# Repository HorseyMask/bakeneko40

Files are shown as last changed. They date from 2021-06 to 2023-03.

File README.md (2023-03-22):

# bakeneko40

## On Hold / WIP. Nothing here works (probably), please don't actually try to make this

### Do have interest in working on this again, but still consider this on hold until further work is done.

40% verison of the bakenkeo40 keyboard by kkatano. 

PCB is still in testing and unconfirmed to work, but otherwise project is mostly done.

Case is a bit too big for plate and pcb. Either edit case or use foam between pcb and plate to allow more room for oring.

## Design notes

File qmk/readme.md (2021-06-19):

# bakeuma40

bakeuma40

*A short description of the keyboard/project*

* Keyboard Maintainer: [Horace](https://github.com/yourusername)
* Hardware Supported: *The PCBs, controllers supported*
* Hardware Availability: *Links to where you can find this hardware*

Make example for this keyboard (after setting up your build environment):

    make bakeuma40:default

Flashing example for this keyboard:

    make bakeuma40:default:flash

See the [build environment setup](https://docs.qmk.fm/#/getting_started_build_tools) and the [make instructions](https://docs.qmk.fm/#/getting_started_make_guide) for more information. Brand new to QMK? Start with our [Complete Newbs Guide](https://docs.qmk.fm/#/newbs).

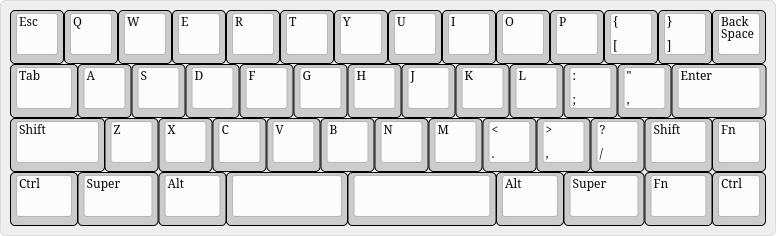
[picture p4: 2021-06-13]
keyboard-layout.png

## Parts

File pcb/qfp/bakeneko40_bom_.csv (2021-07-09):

Component | Description | Part | References | Value | Footprint | Quantity Per PCB | Datasheet
1 | Unpolarized capacitor, small symbol | C_Small | C6 C7 | 22pF | C_0805_2012Metric | 2 | ~
2 | Unpolarized capacitor, small symbol | C_Small | C2 C3 C4 | 0.1uF | C_0805_2012Metric | 3 | ~
3 | Unpolarized capacitor, small symbol | C_Small | C1 | 1uF | C_0805_2012Metric | 1 | ~
4 | Unpolarized capacitor, small symbol | C_Small | C5 | 10uF | C_0805_2012Metric | 1 | ~
5 | Diode, small symbol | D_Small | D1 D2 D3 D4 D5 D6 D7 D8 D9 D10 D11 D12 D13 D14 D15 D16 D17 D18 D19 D20 D21 D22 D23 D24 D25 D26 D27 D28 D29 D30 D31 D32 D33 D34 D35 D36 D37 D38 D39 D40 D41 D42 D43 D44 D45 D46 D47 D48 D49 | SOD-123 | D_SOD-123 | 49 | ~
6 | Resettable fuse, polymeric positive temperature coefficient, small symbol | Polyfuse_Small | F1 | 500mA | Fuse_1206_3216Metric | 1 | ~
7 | Atmel 6-pin ISP connector | AVR-ISP-6 | J2 | AVR-ISP-6 | Reset_Pretty-Mask | 1 | ~
8 | Generic connector, single row, 01x04, script generated (kicad-library-utils/schlib/autogen/connector/) | Conn_01x04 | J1 | JST SH 4-pin | JST-SR-4 | 1 | ~
9 |  | MX-NoLED | MX1 MX2 MX3 MX4 MX5 MX6 MX7 MX8 MX9 MX10 MX11 MX12 MX13 MX14 MX16 MX17 MX18 MX19 MX20 MX21 MX22 MX23 MX24 MX25 MX26 MX29 MX30 MX31 MX32 MX33 MX34 MX35 MX36 MX37 MX38 MX40 MX49 | MX-NoLED | MXOnly-1U-NoLED | 37
10 |  | MX-NoLED | MX15 MX39 MX41 MX43 MX46 MX48 | MX-NoLED | MXOnly-1.25U-NoLED | 6
11 |  | MX-NoLED | MX27 MX28 | MX-NoLED | MXOnly-1.75U-NoLED | 2
12 |  | MX-NoLED | MX42 MX47 | MX-NoLED | MXOnly-1.5U-NoLED | 2
13 |  | MX-NoLED | MX44 | MX-NoLED | MXOnly-2.25U-ReversedStabilizers-NoLED | 1
14 |  | MX-NoLED | MX45 | MX-NoLED | MXOnly-2.75U-ReversedStabilizers-NoLED | 1
15 | Resistor, small symbol | R_Small | R2 R3 | 22 | R_0805_2012Metric | 2 | ~
16 | Resistor, small symbol | R_Small | R1 R4 | 10k | R_0805_2012Metric | 2 | ~
17 | Push button switch, generic, two pins | SW_Push | SW1 | SW_Push | SKQG-1155865 | 1 | ~
18 | 16MHz, 32kB Flash, 1kB SRAM, 1kB EEPROM, TQFP-32 | ATmega32U2-AU | U1 | ATmega32U2-AU | TQFP-32_7x7mm_P0.8mm | 1 | http://ww1.microchip.com/downloads/en/DeviceDoc/doc7799.pdf
19 | ESD Protection Diodes with Low Clamping Voltage, SOT-23-6 | SRV05-4 | U2 | SRV05-4 | SOT-23-6 | 1 | http://www.onsemi.com/pub/Collateral/SRV05-4-D.PDF
20 | Four pin crystal, GND on pins 2 and 4, small symbol | Crystal_GND24_Small | Y1 | 16MHz | Crystal_SMD_3225-4Pin_3.2x2.5mm | 1 | ~
Component Groups: | 20
Component Count: | 116
Fitted Components: | 116
Number of PCBs: | 1
Total components: | 116
Schematic Version:
Schematic Date:
PCB Variant: | default
BoM Date: | Fri 09 Jul 2021 03:37:36 PM KST
Schematic Source: | bakeneko40.sch
KiCad Version: | Eeschema 5.1.10

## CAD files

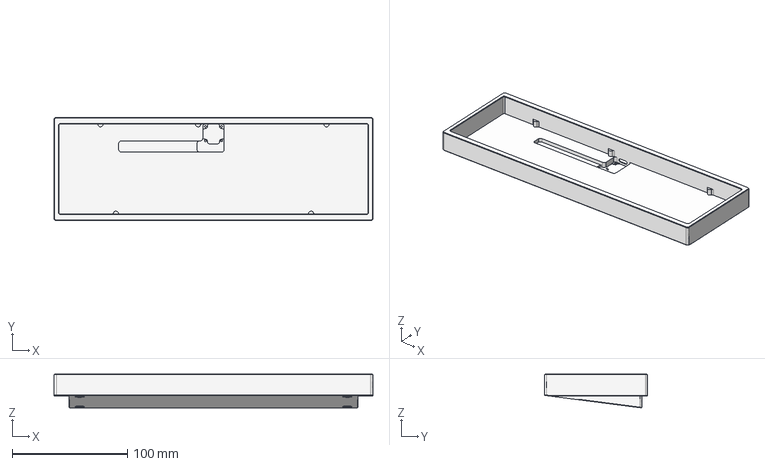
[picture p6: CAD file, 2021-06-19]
case/bakeneko40.step
277.1 x 89.6 x 29.4 mm

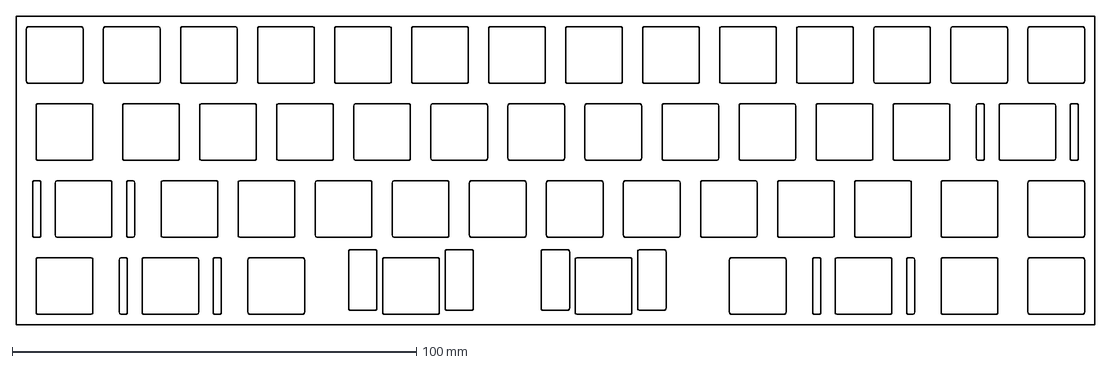
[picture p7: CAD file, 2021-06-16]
plate/bake40_normal.dxf
266.7 x 76.2 mm

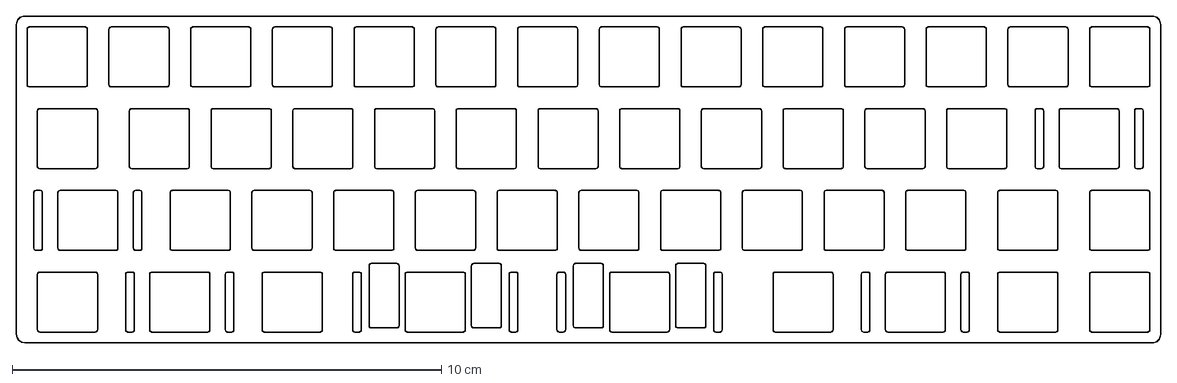
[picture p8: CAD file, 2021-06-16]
plate/bake40_extreme.dxf
26.7 x 7.62 cm

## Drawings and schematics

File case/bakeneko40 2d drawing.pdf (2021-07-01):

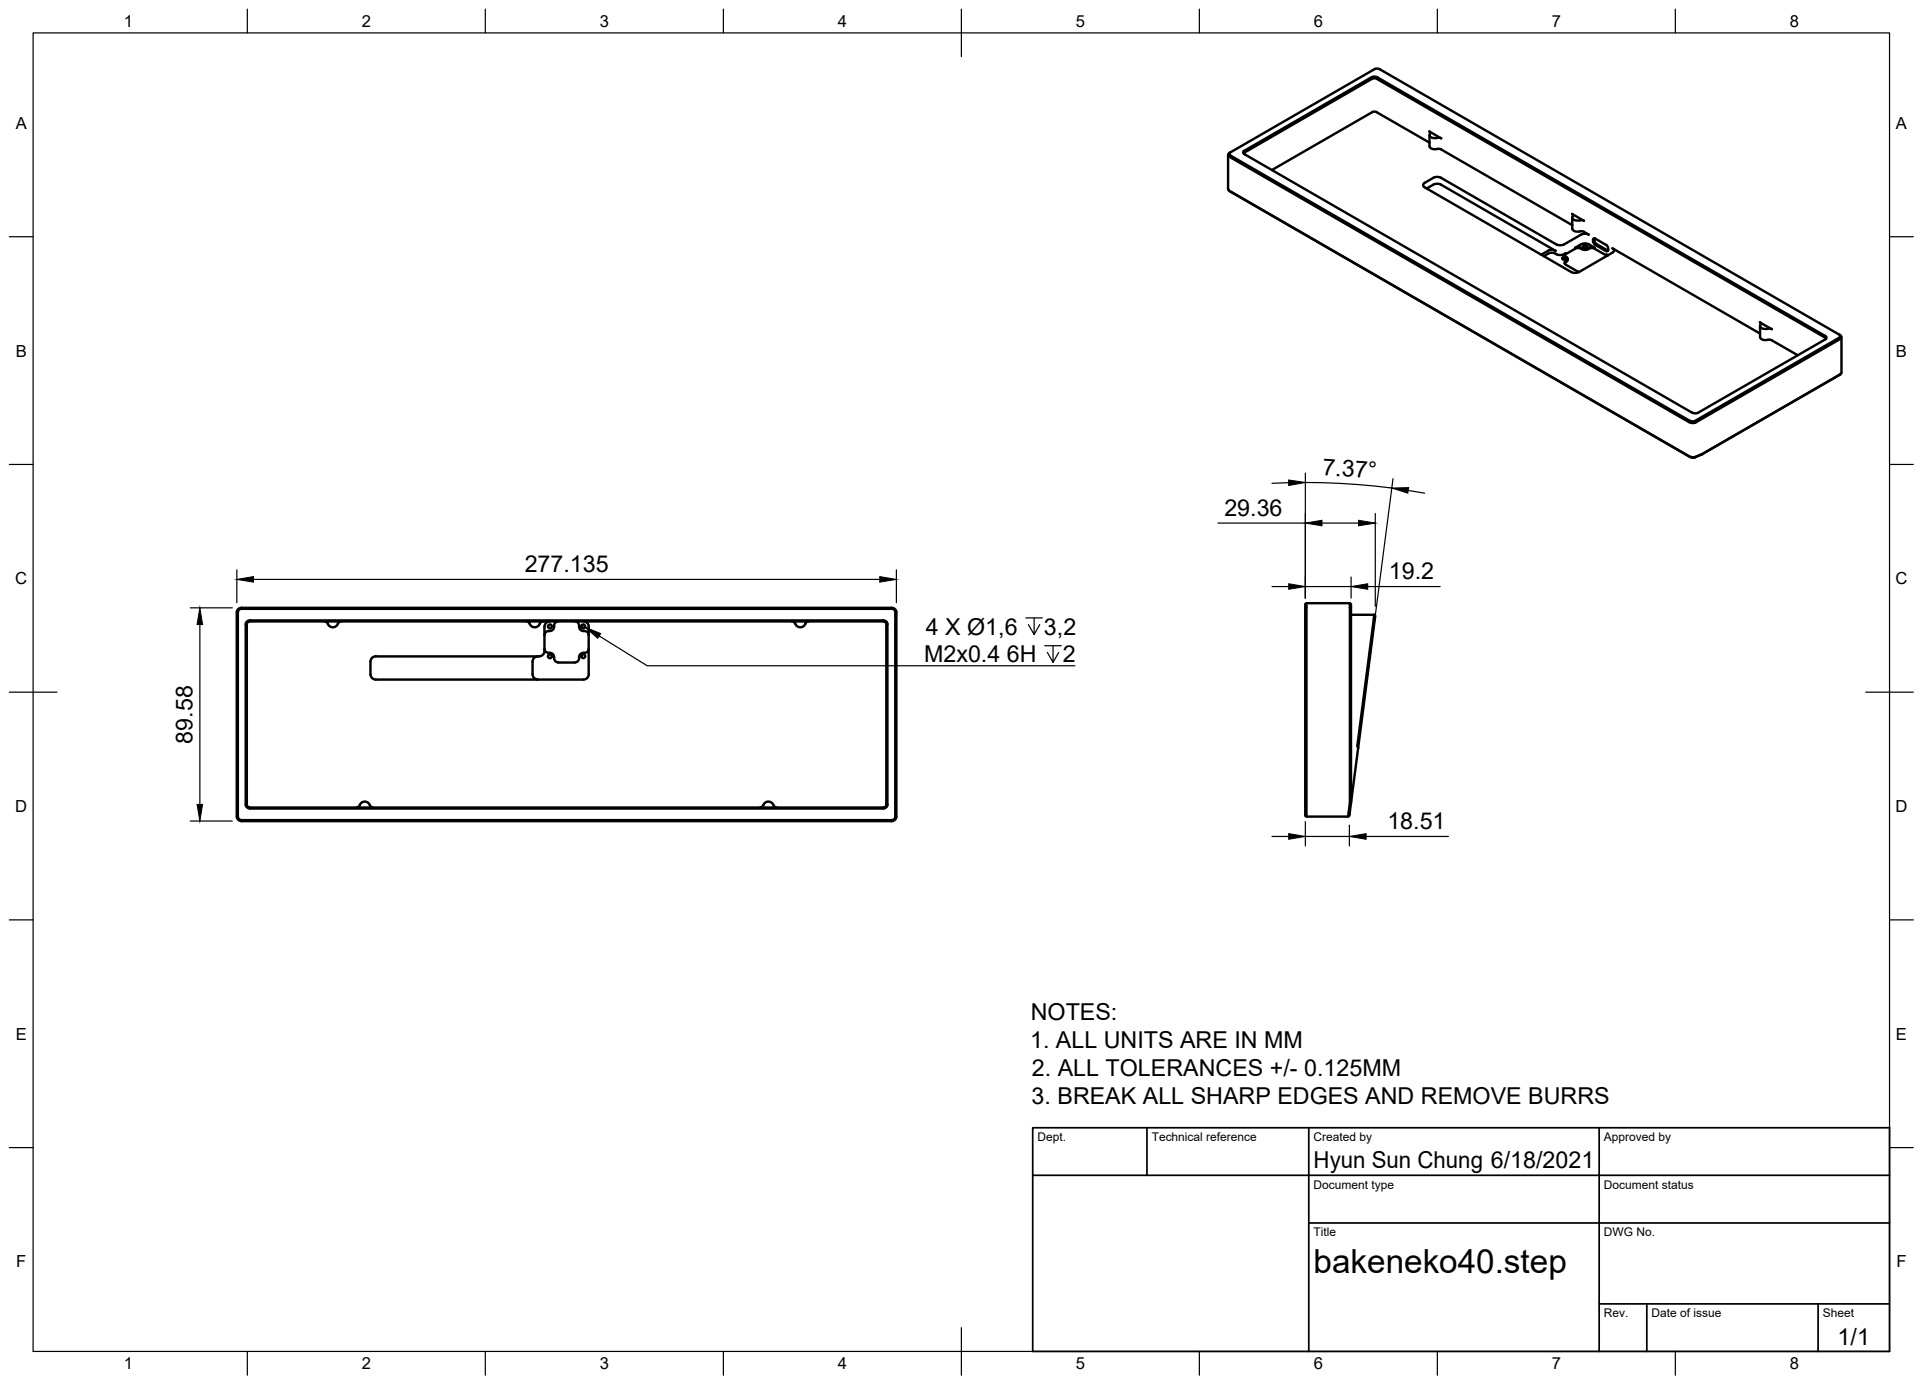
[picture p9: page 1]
Title; DWG No.; Rev.; Date of issue; Sheet

NOTES:
1. ALL UNITS ARE IN MM
2. ALL TOLERANCES +/- 0.125MM
3. BREAK ALL SHARP EDGES AND REMOVE BURRS

Dept. | Technical reference | Created by Hyun Sun Chung 6/18/2021 | Approved by

Document type | Document status

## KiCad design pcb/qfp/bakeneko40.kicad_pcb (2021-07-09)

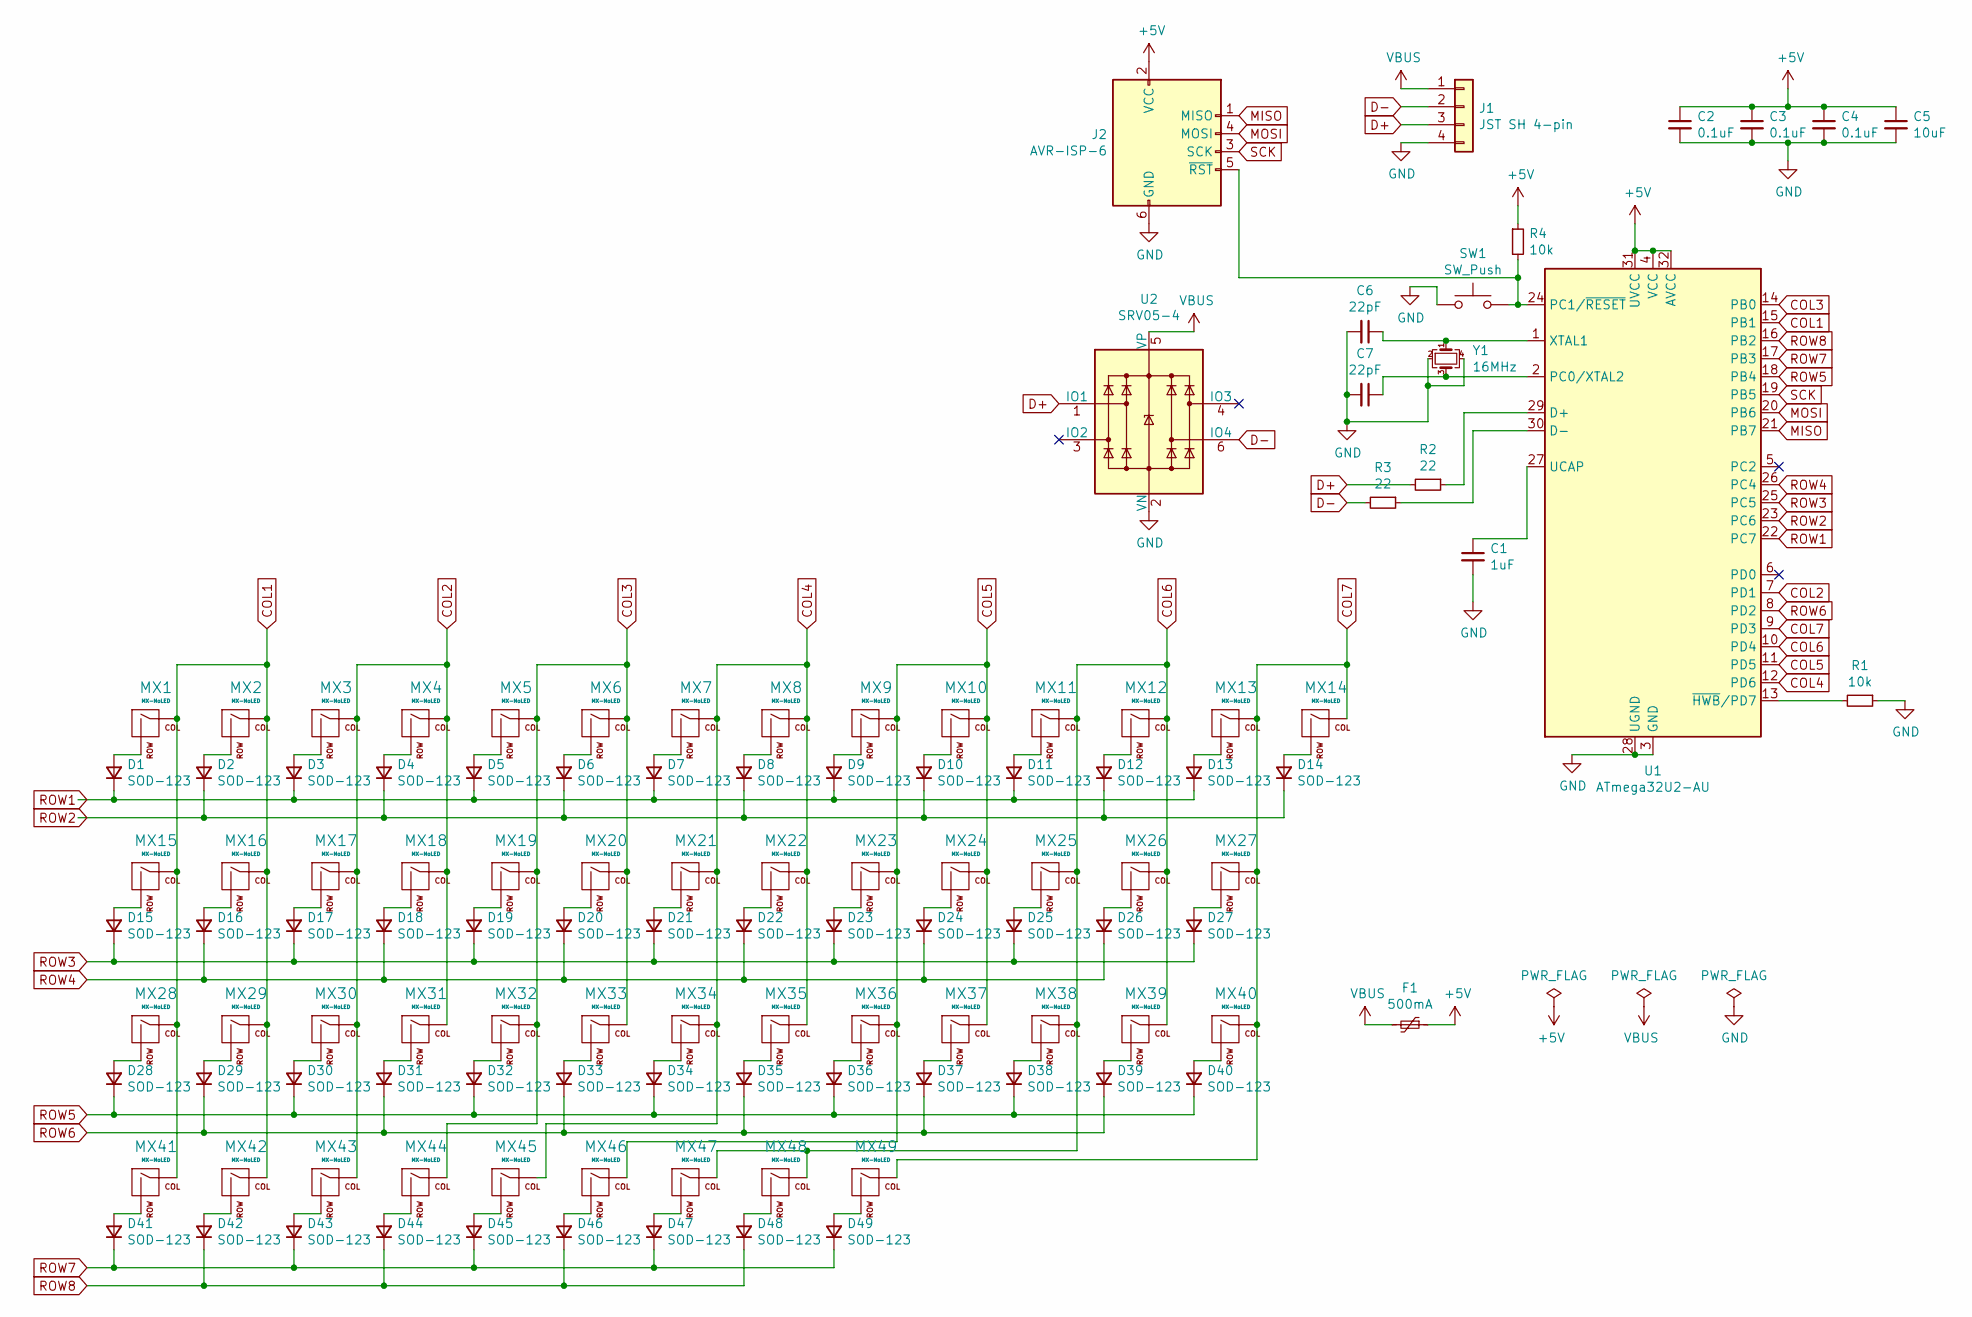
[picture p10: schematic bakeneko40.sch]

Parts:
C1: 1uF; C_0805_2012Metric
C2, C3, C4: 0.1uF; C_0805_2012Metric
C5: 10uF; C_0805_2012Metric
C6, C7: 22pF; C_0805_2012Metric
D1, D2, D3, D4, D5, D6, D7, D8, D9, D10, D11, D12, D13, D14, D15, D16, D17, D18, D19, D20, D21, D22, D23, D24, D25, D26, D27, D28, D29, D30, D31, D32, D33, D34, D35, D36, D37, D38, D39, D40, D41, D42, D43, D44, D45, D46, D47, D48, D49: SOD-123; D_SOD-123
F1: 500mA; Fuse_1206_3216Metric
J1: JST SH 4-pin; JST-SR-4
J2: AVR-ISP-6; Reset_Pretty-Mask
MX1, MX2, MX3, MX4, MX5, MX6, MX7, MX8, MX9, MX10, MX11, MX12, MX13, MX14, MX16, MX17, MX18, MX19, MX20, MX21, MX22, MX23, MX24, MX25, MX26, MX29, MX30, MX31, MX32, MX33, MX34, MX35, MX36, MX37, MX38, MX40, MX49: MX-NoLED; MXOnly-1U-NoLED
MX15, MX39, MX41, MX43, MX46, MX48: MX-NoLED; MXOnly-1.25U-NoLED
MX27, MX28: MX-NoLED; MXOnly-1.75U-NoLED
MX42, MX47: MX-NoLED; MXOnly-1.5U-NoLED
MX44: MX-NoLED; MXOnly-2.25U-ReversedStabilizers-NoLED
MX45: MX-NoLED; MXOnly-2.75U-ReversedStabilizers-NoLED
R1, R4: 10k; R_0805_2012Metric
R2, R3: 22; R_0805_2012Metric
SW1: SW_Push; SKQG-1155865
U1: ATmega32U2-AU; TQFP-32_7x7mm_P0.8mm
U2: SRV05-4; SOT-23-6
Y1: 16MHz; Crystal_SMD_3225-4Pin_3.2x2.5mm

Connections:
+5V: C2.1, C3.1, C4.1, C5.1, F1.1, J2.2 (VCC), R4.1, U1.4 (VCC), U1.31 (UVCC), U1.32 (AVCC)
COL1: MX1.1 (COL), MX2.1 (COL), MX15.1 (COL), MX16.1 (COL), MX28.1 (COL), MX29.1 (COL), MX41.1 (COL), MX42.1 (COL), U1.15 (PB1)
COL2: MX3.1 (COL), MX4.1 (COL), MX17.1 (COL), MX18.1 (COL), MX30.1 (COL), MX31.1 (COL), MX43.1 (COL), U1.7 (PD1)
COL3: MX5.1 (COL), MX6.1 (COL), MX19.1 (COL), MX20.1 (COL), MX32.1 (COL), MX33.1 (COL), MX44.1 (COL), U1.14 (PB0)
COL4: MX7.1 (COL), MX8.1 (COL), MX21.1 (COL), MX22.1 (COL), MX34.1 (COL), MX35.1 (COL), MX45.1 (COL), U1.12 (PD6)
COL5: MX9.1 (COL), MX10.1 (COL), MX23.1 (COL), MX24.1 (COL), MX36.1 (COL), MX37.1 (COL), MX46.1 (COL), U1.11 (PD5)
COL6: MX11.1 (COL), MX12.1 (COL), MX25.1 (COL), MX26.1 (COL), MX38.1 (COL), MX39.1 (COL), MX47.1 (COL), MX48.1 (COL), U1.10 (PD4)
COL7: MX13.1 (COL), MX14.1 (COL), MX27.1 (COL), MX40.1 (COL), MX49.1 (COL), U1.9 (PD3)
D+: J1.3, R2.2, U2.1 (IO1)
D-: J1.2, R3.2, U2.6 (IO4)
GND: C1.2, C2.2, C3.2, C4.2, C5.2, C6.2, C7.2, J1.4, J2.6 (GND), R1.1, SW1.1, U1.3 (GND), U1.28 (UGND), U2.2 (VN), Y1.2, Y1.4
MISO: J2.1 (MISO), U1.21 (PB7)
MOSI: J2.4 (MOSI), U1.20 (PB6)
unnamed: C1.1, U1.27 (UCAP)
unnamed: C6.1, U1.1 (XTAL1), Y1.1
unnamed: C7.1, U1.2 (PC0/XTAL2), Y1.3
unnamed: D1.2 (A), MX1.2 (ROW)
unnamed: D2.2 (A), MX2.2 (ROW)
unnamed: D3.2 (A), MX3.2 (ROW)
unnamed: D4.2 (A), MX4.2 (ROW)
unnamed: D5.2 (A), MX5.2 (ROW)
unnamed: D6.2 (A), MX6.2 (ROW)
unnamed: D7.2 (A), MX7.2 (ROW)
unnamed: D8.2 (A), MX8.2 (ROW)
unnamed: D9.2 (A), MX9.2 (ROW)
unnamed: D10.2 (A), MX10.2 (ROW)
unnamed: D11.2 (A), MX11.2 (ROW)
unnamed: D12.2 (A), MX12.2 (ROW)
unnamed: D13.2 (A), MX13.2 (ROW)
unnamed: D14.2 (A), MX14.2 (ROW)
unnamed: D15.2 (A), MX15.2 (ROW)
unnamed: D16.2 (A), MX16.2 (ROW)
unnamed: D17.2 (A), MX17.2 (ROW)
unnamed: D18.2 (A), MX18.2 (ROW)
unnamed: D19.2 (A), MX19.2 (ROW)
unnamed: D20.2 (A), MX20.2 (ROW)
unnamed: D21.2 (A), MX21.2 (ROW)
unnamed: D22.2 (A), MX22.2 (ROW)
unnamed: D23.2 (A), MX23.2 (ROW)
unnamed: D24.2 (A), MX24.2 (ROW)
unnamed: D25.2 (A), MX25.2 (ROW)
unnamed: D26.2 (A), MX26.2 (ROW)
unnamed: D27.2 (A), MX27.2 (ROW)
unnamed: D28.2 (A), MX28.2 (ROW)
unnamed: D29.2 (A), MX29.2 (ROW)
unnamed: D30.2 (A), MX30.2 (ROW)
unnamed: D31.2 (A), MX31.2 (ROW)
unnamed: D32.2 (A), MX32.2 (ROW)
unnamed: D33.2 (A), MX33.2 (ROW)
unnamed: D34.2 (A), MX34.2 (ROW)
unnamed: D35.2 (A), MX35.2 (ROW)
unnamed: D36.2 (A), MX36.2 (ROW)
unnamed: D37.2 (A), MX37.2 (ROW)
unnamed: D38.2 (A), MX38.2 (ROW)
unnamed: D39.2 (A), MX39.2 (ROW)
unnamed: D40.2 (A), MX40.2 (ROW)
unnamed: D41.2 (A), MX41.2 (ROW)
unnamed: D42.2 (A), MX42.2 (ROW)
unnamed: D43.2 (A), MX43.2 (ROW)
unnamed: D44.2 (A), MX44.2 (ROW)
unnamed: D45.2 (A), MX45.2 (ROW)
unnamed: D46.2 (A), MX46.2 (ROW)
unnamed: D47.2 (A), MX47.2 (ROW)
unnamed: D48.2 (A), MX48.2 (ROW)
unnamed: D49.2 (A), MX49.2 (ROW)
unnamed: J2.5 (~RST), R4.2, SW1.2, U1.24 (PC1/~RESET)
unnamed: R1.2, U1.13 (~HWB~/PD7)
unnamed: R2.1, U1.29 (D+)
unnamed: R3.1, U1.30 (D-)
ROW1: D1.1 (K), D3.1 (K), D5.1 (K), D7.1 (K), D9.1 (K), D11.1 (K), D13.1 (K), U1.22 (PC7)
ROW2: D2.1 (K), D4.1 (K), D6.1 (K), D8.1 (K), D10.1 (K), D12.1 (K), D14.1 (K), U1.23 (PC6)
ROW3: D15.1 (K), D17.1 (K), D19.1 (K), D21.1 (K), D23.1 (K), D25.1 (K), D27.1 (K), U1.25 (PC5)
ROW4: D16.1 (K), D18.1 (K), D20.1 (K), D22.1 (K), D24.1 (K), D26.1 (K), U1.26 (PC4)
ROW5: D28.1 (K), D30.1 (K), D32.1 (K), D34.1 (K), D36.1 (K), D38.1 (K), D40.1 (K), U1.18 (PB4)
ROW6: D29.1 (K), D31.1 (K), D33.1 (K), D35.1 (K), D37.1 (K), D39.1 (K), U1.8 (PD2)
ROW7: D41.1 (K), D43.1 (K), D45.1 (K), D47.1 (K), D49.1 (K), U1.17 (PB3)
ROW8: D42.1 (K), D44.1 (K), D46.1 (K), D48.1 (K), U1.16 (PB2)
SCK: J2.3 (SCK), U1.19 (PB5)
VBUS: F1.2, J1.1, U2.5 (VP)

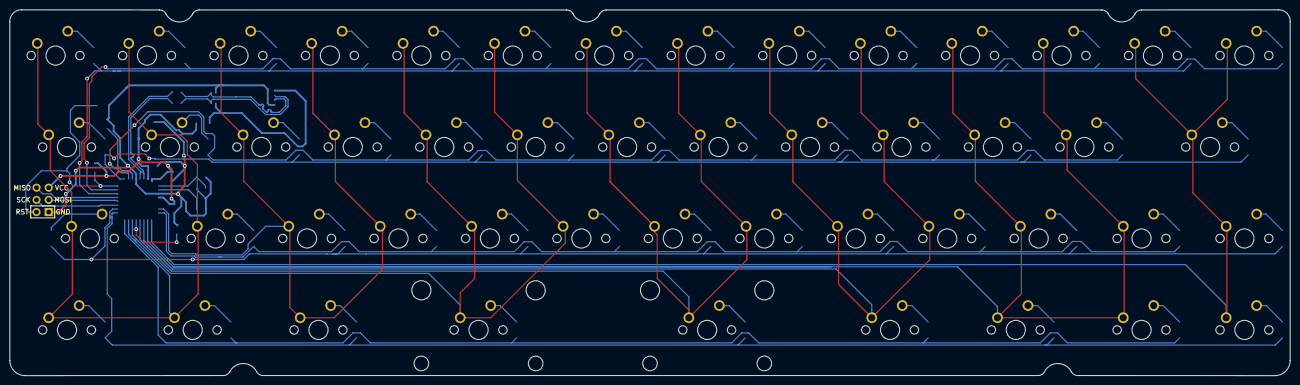
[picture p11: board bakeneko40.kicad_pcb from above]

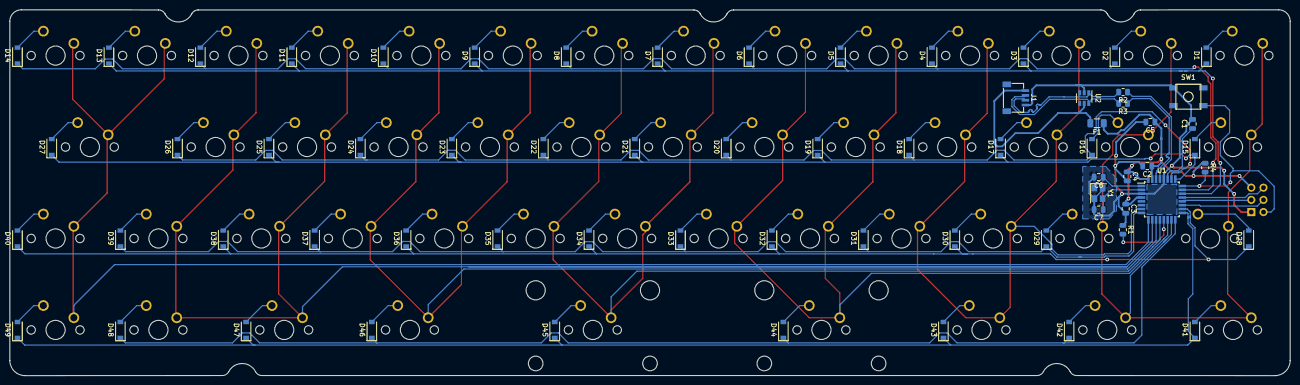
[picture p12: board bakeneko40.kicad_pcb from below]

Board: 2 copper layers, 266.7 x 76.2 mm, 116 parts (66 on the bottom side), 79 nets.

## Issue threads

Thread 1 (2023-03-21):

support

nottoledo, 2023-03-21:
Are there any PCB's on the market that fit in this case?

HorseyMask, 2023-03-21:
Fixing misclicking close with comment as well as answering
No as I know of. I was working on a pcb before putting a hiatus on this project. Though I am (hopefully) planning to restart working on this again soon.

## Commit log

2021-06-13 add submodules
    [bakeneko-40-case.step v12.step, bakeneko40.kicad_pcb, bakeneko40.sch]
2021-06-13 layout+pcb work
    [bakeneko40.sch]
2021-06-13 full alpha case add
    [bakeneko-40-case_adele.step v3.step]
2021-06-13 sch updates
    [bakeneko40.kicad_pcb, bakeneko40.sch, matrix.kicad_pcb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]
2021-06-15 pcb routing
    [bakeneko40.kicad_pcb, bakeneko40.sch]
2021-06-16 finished pcb
    [PickAndPlace_bakeneko40_2021-06-15.csv, bake40.dxf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]
2021-06-16 pcb cut edits
    [bake40.dxf, bake40_extreme.dxf, bake40_normal.dxf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]
2021-06-18 final pcb and case
    [PickAndPlace_bakeneko40_2021-06-15.csv, PickAndPlace_bakeneko40_2021-06-18.csv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]
2021-06-19 qmk code
    [bakeneko40.step]
2021-07-01 qfp pcb
    [PickAndPlace_bakeneko40_2021-06-18.csv, PickAndPlace_bakeneko40_2021-06-28.csv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]
2021-07-09 pcb and qmk edits
    [PickAndPlace_bakeneko40_2021-06-28.csv, PickAndPlace_bakeneko40_2021-07-09.csv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]
